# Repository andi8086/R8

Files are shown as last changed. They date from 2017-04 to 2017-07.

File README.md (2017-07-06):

## Picocom configuration ##

Start picocom with:

```
picocom --send-cmd "sx -Xb" -b 19200 -d 8 --emap lfcr /dev/ttyUSB0
```

## XMODEM File transfer ##

```
REICHEL R8
6502 CPU @ 2 MHz
32K RAM         
MONITOR (c)1976 Steve Wozniak
ADAPTED 2017 Andreas J. Reichel
\                              
F900R
F900: 20XMOD
CCCC
*** file: /home/andreas/Projects/6502/testprogs/test1.bin
$ sx -Xb /home/andreas/Projects/6502/testprogs/test1.bin 
Sending /home/andreas/Projects/6502/testprogs/test1.bin, 0 blocks: Give your local XMODEM receive command now.
Xmodem sectors/kbytes sent:   0/ 0kRetry 0: NAK on sector
Bytes Sent:    128   BPS:75                              

Transfer complete

*** exit status: 0 ***
OK
\
1000.1020
1000: A9 0E 85 20 A9 10 85 21
1008: 20 2F C0 4C 00 F8 48 69
1010: 2C 20 49 20 61 6D 20 74
1018: 68 65 20 66 69 72 73 74
1020: 20                     
1000    
1000: A9
Hi, I am the first program transfered via serial :)
\                                                  
```

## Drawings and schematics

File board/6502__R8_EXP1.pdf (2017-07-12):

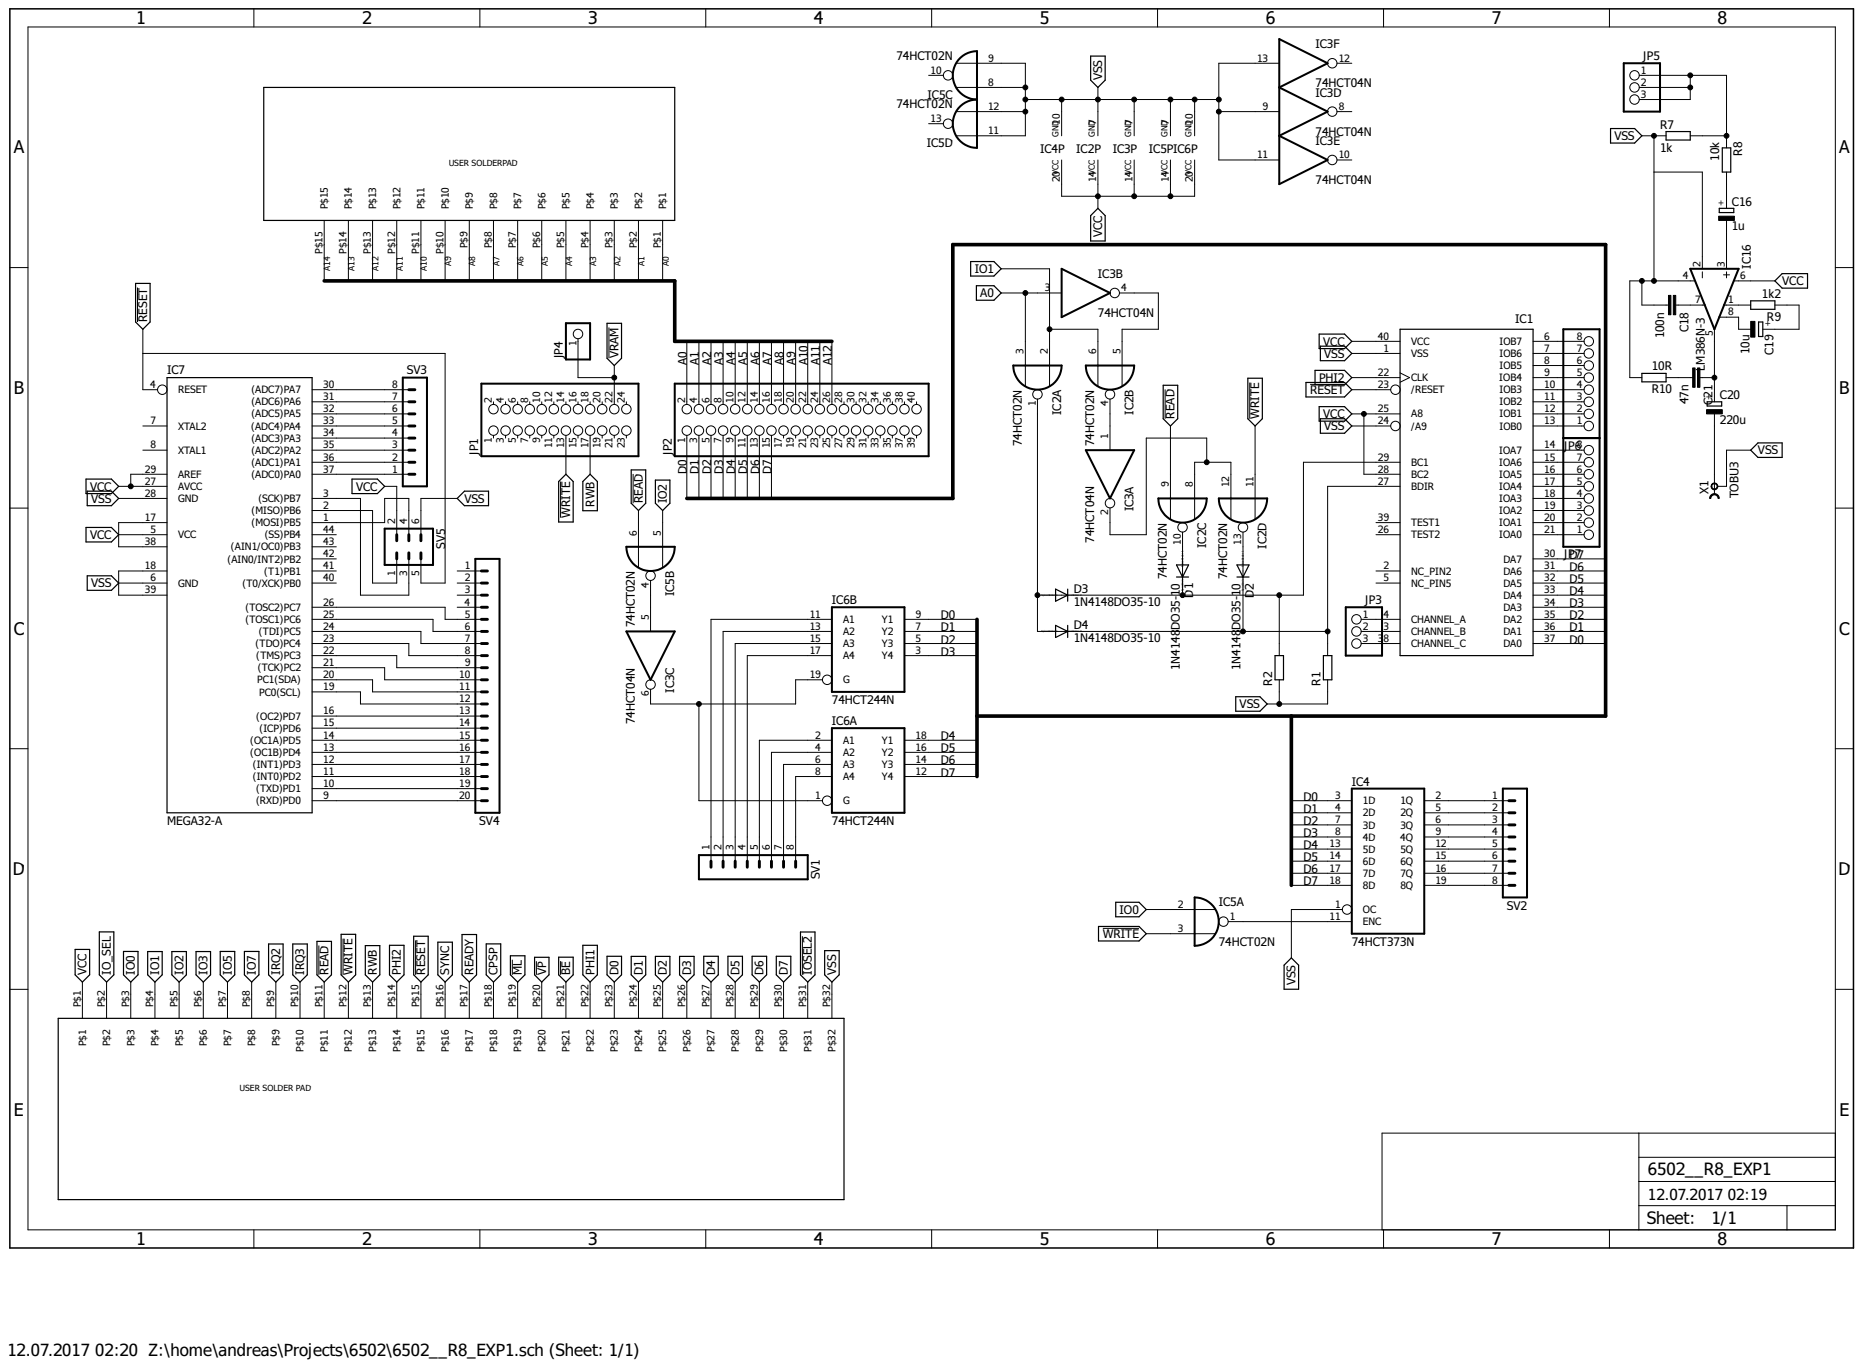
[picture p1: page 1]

5 | 44
38 | 43

SYNC READY CPSP ML VP

12.07.2017 02:20 Z:\home\andreas\Projects\6502\6502__R8_EXP1.sch (Sheet: 1/1)

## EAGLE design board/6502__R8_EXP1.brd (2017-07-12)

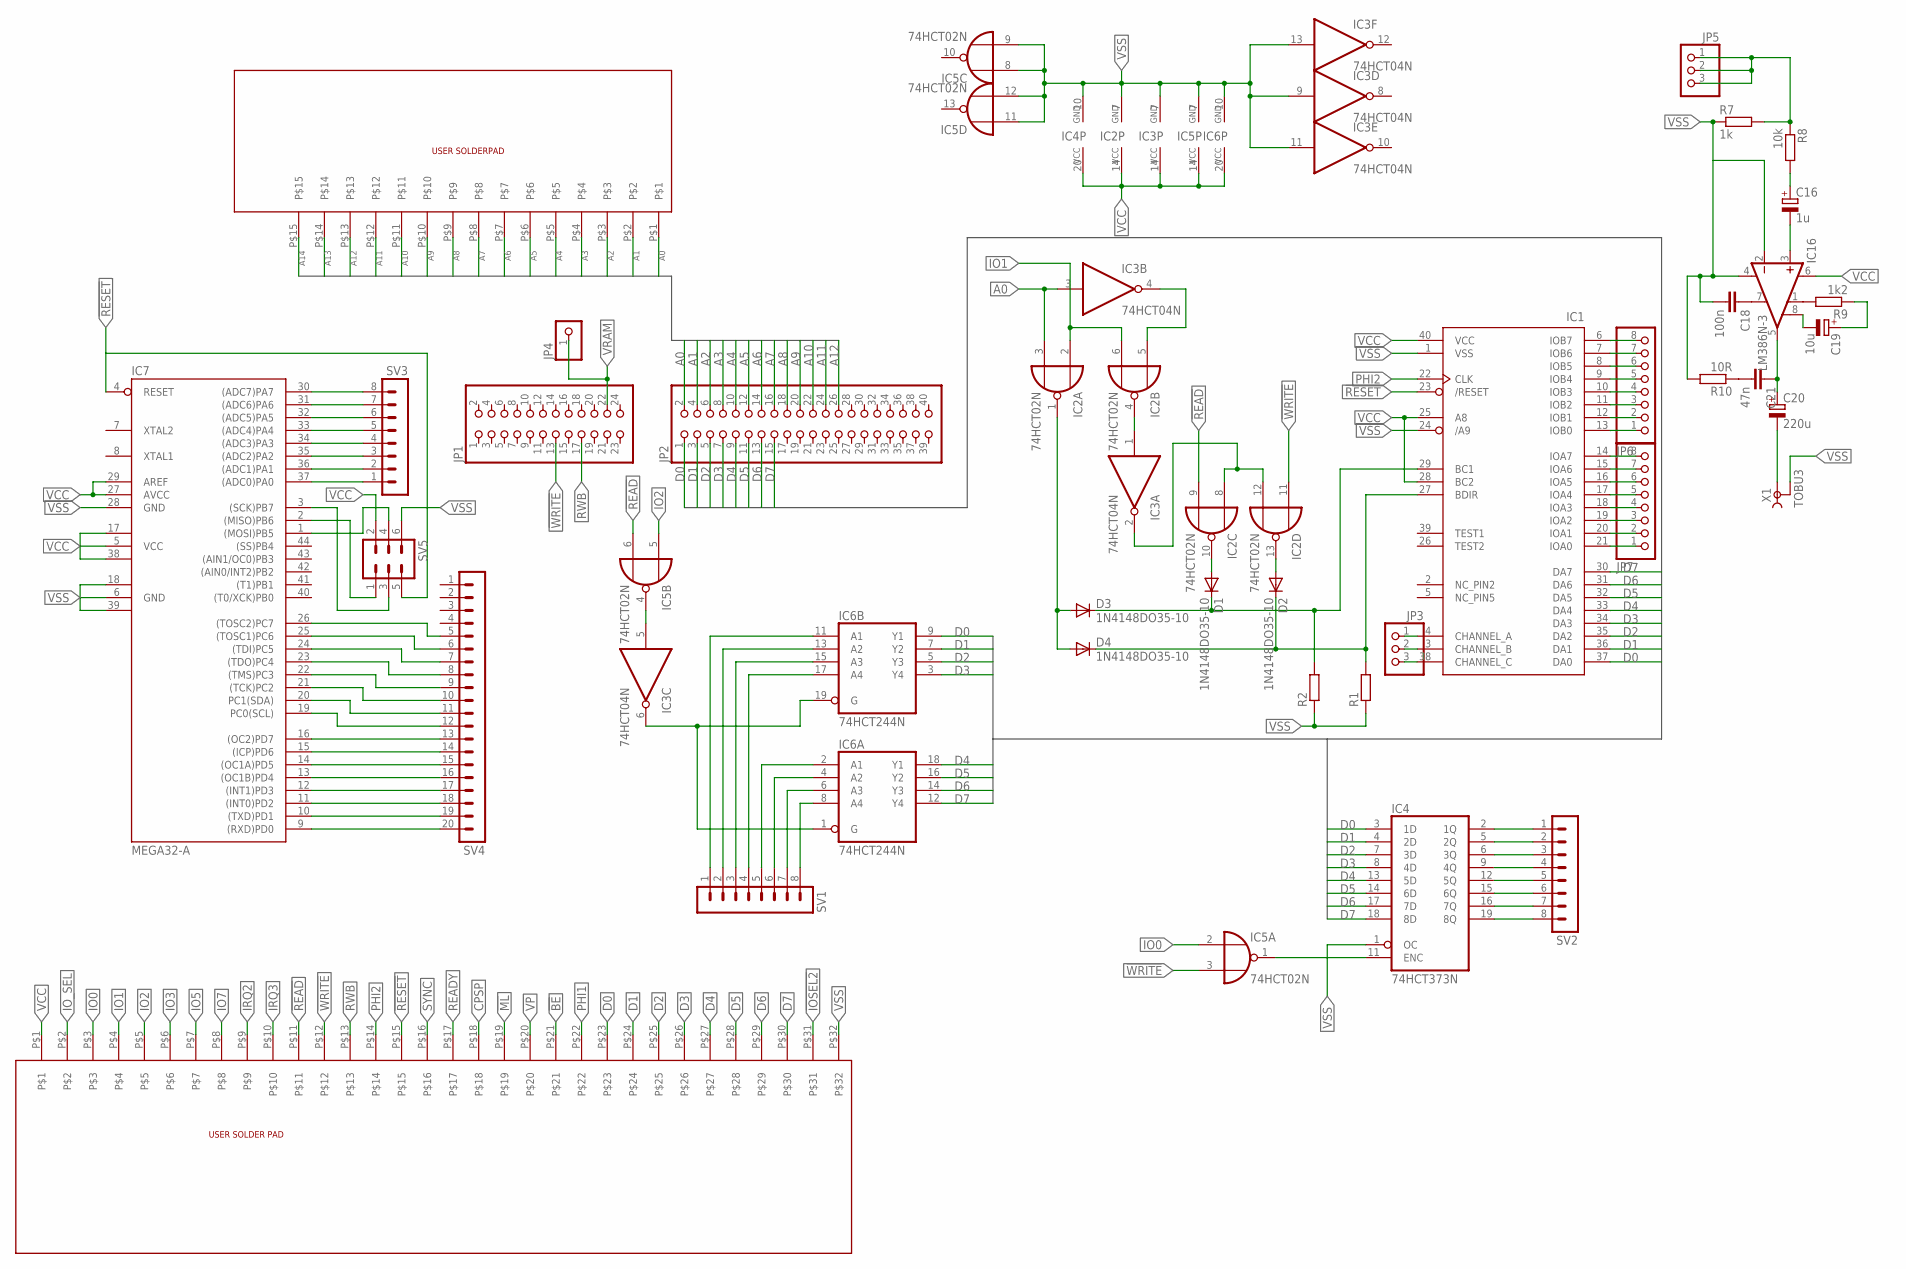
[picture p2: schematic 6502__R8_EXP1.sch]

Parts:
C16: 1u; E5-5
C18: 100n; C025-030X050
C19: 10u; E5-5
C20: 220u; E5-5
C21: 47n; C025-030X050
D1, D2, D3, D4: 1N4148DO35-10; DO35-10
IC1: AY-3-8910; DIL40
IC2, IC5: 74HCT02N; DIL14
IC3: 74HCT04N; DIL14
IC4: 74HCT373N; DIL20
IC6: 74HCT244N; DIL20
IC7: MEGA32-A; TQFP44
IC16: LM386N-3; DIL08
JP1: PINHD-2X12; 2X12
JP2: PINHD-2X20; 2X20
JP3, JP5: PINHD-1X3; 1X03
JP4: PINHD-1X1; 1X01
JP6, JP7: PINHD-1X8; 1X08
R1, R2: R-EU_0204/7; 0204/7
R7: 1k; 0207/12
R8: 10k; 0207/12
R9: 1k2; 0207/12
R10: 10R; 0207/12
SV1, SV2, SV3: MA08-1
SV4: MA20-1
SV5: MA03-2
U$2: SOLDERPAD
U$3: SOLDERPAD2
X1: TOBU3

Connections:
!BE: U$2.P$21
!IOSEL2: U$2.P$31
!ML: U$2.P$19
!READ: IC2.9 (I1), IC5.6 (I1), U$2.P$11
!RESET: IC1.23 (/RESET), IC7.4 (RESET), SV5.5, U$2.P$15
!VP: U$2.P$20
!VRAM: JP1.22, JP4.1
!WRITE: IC2.11 (I0), IC5.3 (I1), JP1.13, U$2.P$12
A0: IC2.3 (I1), IC3.3 (I), JP2.2, U$3.P$1
A1: JP2.4, U$3.P$2
A2: JP2.6, U$3.P$3
A3: JP2.8, U$3.P$4
A4: JP2.10, U$3.P$5
A5: JP2.12, U$3.P$6
A6: JP2.14, U$3.P$7
A7: JP2.16, U$3.P$8
A8: JP2.18, U$3.P$9
A9: JP2.20, U$3.P$10
A10: JP2.22, U$3.P$11
A11: JP2.24, U$3.P$12
A12: JP2.26, U$3.P$13
A13: U$3.P$14
A14: U$3.P$15
CPSP: U$2.P$18
D0: IC1.37 (DA0), IC4.3 (1D), IC6.9 (Y1), JP2.1, U$2.P$23
D1: IC1.36 (DA1), IC4.4 (2D), IC6.7 (Y2), JP2.3, U$2.P$24
D2: IC1.35 (DA2), IC4.7 (3D), IC6.5 (Y3), JP2.5, U$2.P$25
D3: IC1.34 (DA3), IC4.8 (4D), IC6.3 (Y4), JP2.7, U$2.P$26
D4: IC1.33 (DA4), IC4.13 (5D), IC6.18 (Y1), JP2.9, U$2.P$27
D5: IC1.32 (DA5), IC4.14 (6D), IC6.16 (Y2), JP2.11, U$2.P$28
D6: IC1.31 (DA6), IC4.17 (7D), IC6.14 (Y3), JP2.13, U$2.P$29
D7: IC1.30 (DA7), IC4.18 (8D), IC6.12 (Y4), JP2.15, U$2.P$30
IO0: IC5.2 (I0), U$2.P$3
IO1: IC2.2 (I0), IC2.6 (I1), U$2.P$4
IO2: IC5.5 (I0), U$2.P$5
IO3: U$2.P$6
IO5: U$2.P$7
IO7: U$2.P$8
IO_SEL: U$2.P$2
IRQ2: U$2.P$9
IRQ3: U$2.P$10
unnamed: IC4.11 (ENC), IC5.1 (O)
unnamed: IC6.11 (A1), SV1.1
unnamed: IC2.5 (I0), IC3.4 (O)
unnamed: IC2.4 (O), IC3.1 (I)
unnamed: IC2.8 (I0), IC2.12 (I1), IC3.2 (O)
unnamed: IC6.13 (A2), SV1.2
unnamed: D3.A, D4.A, IC2.1 (O)
unnamed: D1.C, D3.C, IC1.29 (BC1), R2.2
unnamed: D2.C, D4.C, IC1.27 (BDIR), R1.2
unnamed: D1.A, IC2.10 (O)
unnamed: D2.A, IC2.13 (O)
unnamed: IC6.15 (A3), SV1.3
unnamed: IC6.17 (A4), SV1.4
unnamed: IC6.2 (A1), SV1.5
unnamed: IC6.4 (A2), SV1.6
unnamed: IC6.6 (A3), SV1.7
unnamed: IC6.8 (A4), SV1.8
unnamed: IC3.5 (I), IC5.4 (O)
unnamed: IC3.6 (O), IC6.1 (G), IC6.19 (G)
unnamed: IC4.2 (1Q), SV2.1
unnamed: IC4.5 (2Q), SV2.2
unnamed: IC4.6 (3Q), SV2.3
unnamed: IC4.9 (4Q), SV2.4
unnamed: IC4.12 (5Q), SV2.5
unnamed: IC4.15 (6Q), SV2.6
unnamed: IC4.16 (7Q), SV2.7
unnamed: IC4.19 (8Q), SV2.8
unnamed: IC1.4 (CHANNEL_A), JP3.1
unnamed: IC1.3 (CHANNEL_B), JP3.2
unnamed: IC1.38 (CHANNEL_C), JP3.3
unnamed: IC1.13 (IOB0), JP6.1
unnamed: IC7.37 ((ADC0)PA0), SV3.1
unnamed: IC7.36 ((ADC1)PA1), SV3.2
unnamed: IC7.35 ((ADC2)PA2), SV3.3
unnamed: IC7.9 ((RXD)PD0), SV4.20
unnamed: IC7.10 ((TXD)PD1), SV4.19
unnamed: IC7.11 ((INT0)PD2), SV4.18
unnamed: IC7.12 ((INT1)PD3), SV4.17
unnamed: IC7.13 ((OC1B)PD4), SV4.16
unnamed: IC7.14 ((OC1A)PD5), SV4.15
unnamed: IC7.15 ((ICP)PD6), SV4.14
unnamed: IC7.16 ((OC2)PD7), SV4.13
unnamed: IC7.19 (PC0(SCL)), SV4.12
unnamed: IC7.20 (PC1(SDA)), SV4.11
unnamed: IC7.21 ((TCK)PC2), SV4.10
unnamed: IC7.22 ((TMS)PC3), SV4.9
unnamed: IC7.23 ((TDO)PC4), SV4.8
unnamed: IC7.24 ((TDI)PC5), SV4.7
unnamed: IC7.25 ((TOSC1)PC6), SV4.6
unnamed: IC7.26 ((TOSC2)PC7), SV4.5
unnamed: IC7.2 ((MISO)PB6), SV5.1
unnamed: IC7.3 ((SCK)PB7), SV5.3
unnamed: IC7.34 ((ADC3)PA3), SV3.4
unnamed: IC7.1 ((MOSI)PB5), SV5.4
unnamed: IC7.33 ((ADC4)PA4), SV3.5
unnamed: IC7.32 ((ADC5)PA5), SV3.6
unnamed: IC7.31 ((ADC6)PA6), SV3.7
unnamed: IC7.30 ((ADC7)PA7), SV3.8
unnamed: IC1.12 (IOB1), JP6.2
unnamed: IC1.11 (IOB2), JP6.3
unnamed: IC1.10 (IOB3), JP6.4
unnamed: IC1.9 (IOB4), JP6.5
unnamed: IC1.8 (IOB5), JP6.6
unnamed: IC1.7 (IOB6), JP6.7
unnamed: IC1.6 (IOB7), JP6.8
unnamed: IC1.21 (IOA0), JP7.1
unnamed: IC1.20 (IOA1), JP7.2
unnamed: IC1.19 (IOA2), JP7.3
unnamed: IC1.18 (IOA3), JP7.4
unnamed: IC1.17 (IOA4), JP7.5
unnamed: IC1.16 (IOA5), JP7.6
unnamed: IC1.15 (IOA6), JP7.7
unnamed: IC1.14 (IOA7), JP7.8
unnamed: JP5.1, JP5.2, JP5.3, R7.2, R8.1
unnamed: C16.+, R8.2
unnamed: C16.-, IC16.3 (+IN)
unnamed: C18.1, IC16.7 (BYPASS)
unnamed: C19.-, IC16.8 (GAIN)
unnamed: IC16.1 (GAIN), R9.2
unnamed: C19.+, R9.1
unnamed: C20.-, X1.1
unnamed: C20.+, C21.1, IC16.5 (OUT)
unnamed: C21.2, R10.1
PHI1: U$2.P$22
PHI2: IC1.22 (CLK), U$2.P$14
READY: U$2.P$17
RWB: JP1.17, U$2.P$13
SYNC: U$2.P$16
VCC: IC1.25 (A8), IC1.28 (BC2), IC1.40 (VCC), IC2.14 (VCC), IC3.14 (VCC), IC4.20 (VCC), IC5.14 (VCC), IC6.20 (VCC), IC7.5 (VCC), IC7.17 (VCC1), IC7.27 (AVCC), IC7.29 (AREF), IC7.38 (VCC2), IC16.6 (VS), SV5.2, U$2.P$1

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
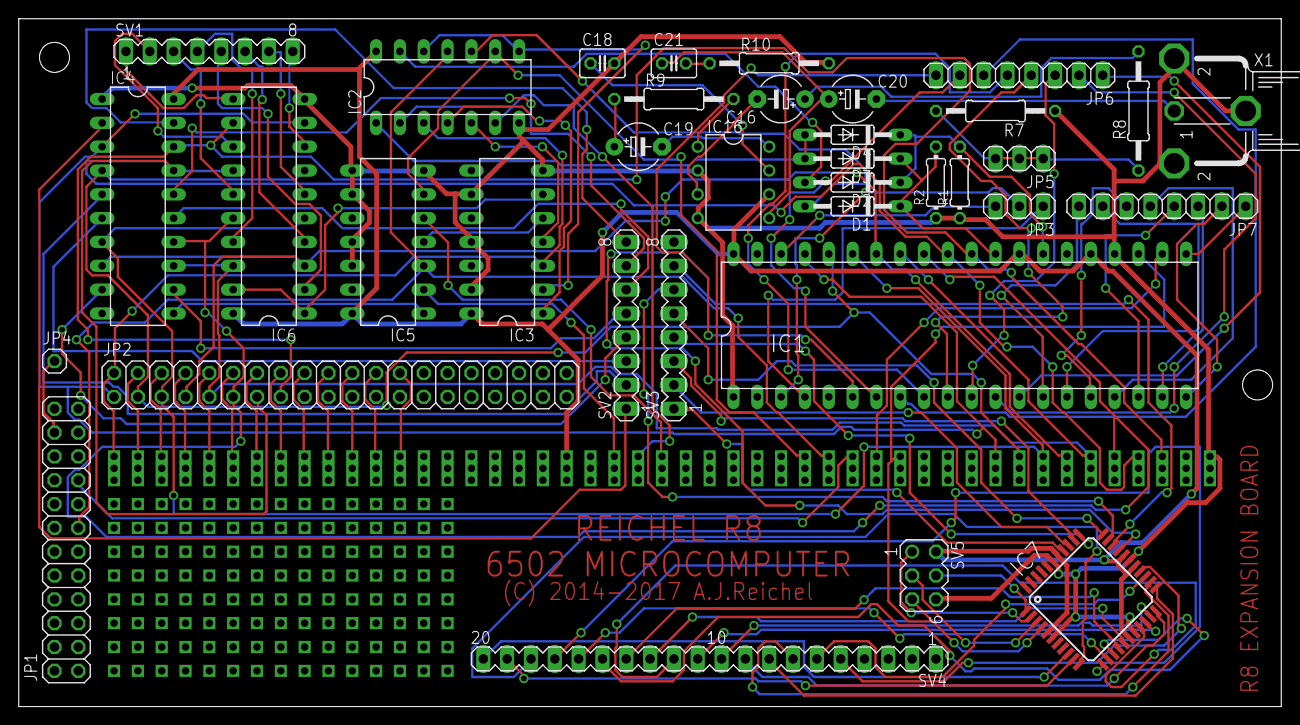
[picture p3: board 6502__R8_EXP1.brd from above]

Board: 2 copper layers, 134.6 x 73.3 mm, 38 parts (0 on the bottom side), 115 nets.

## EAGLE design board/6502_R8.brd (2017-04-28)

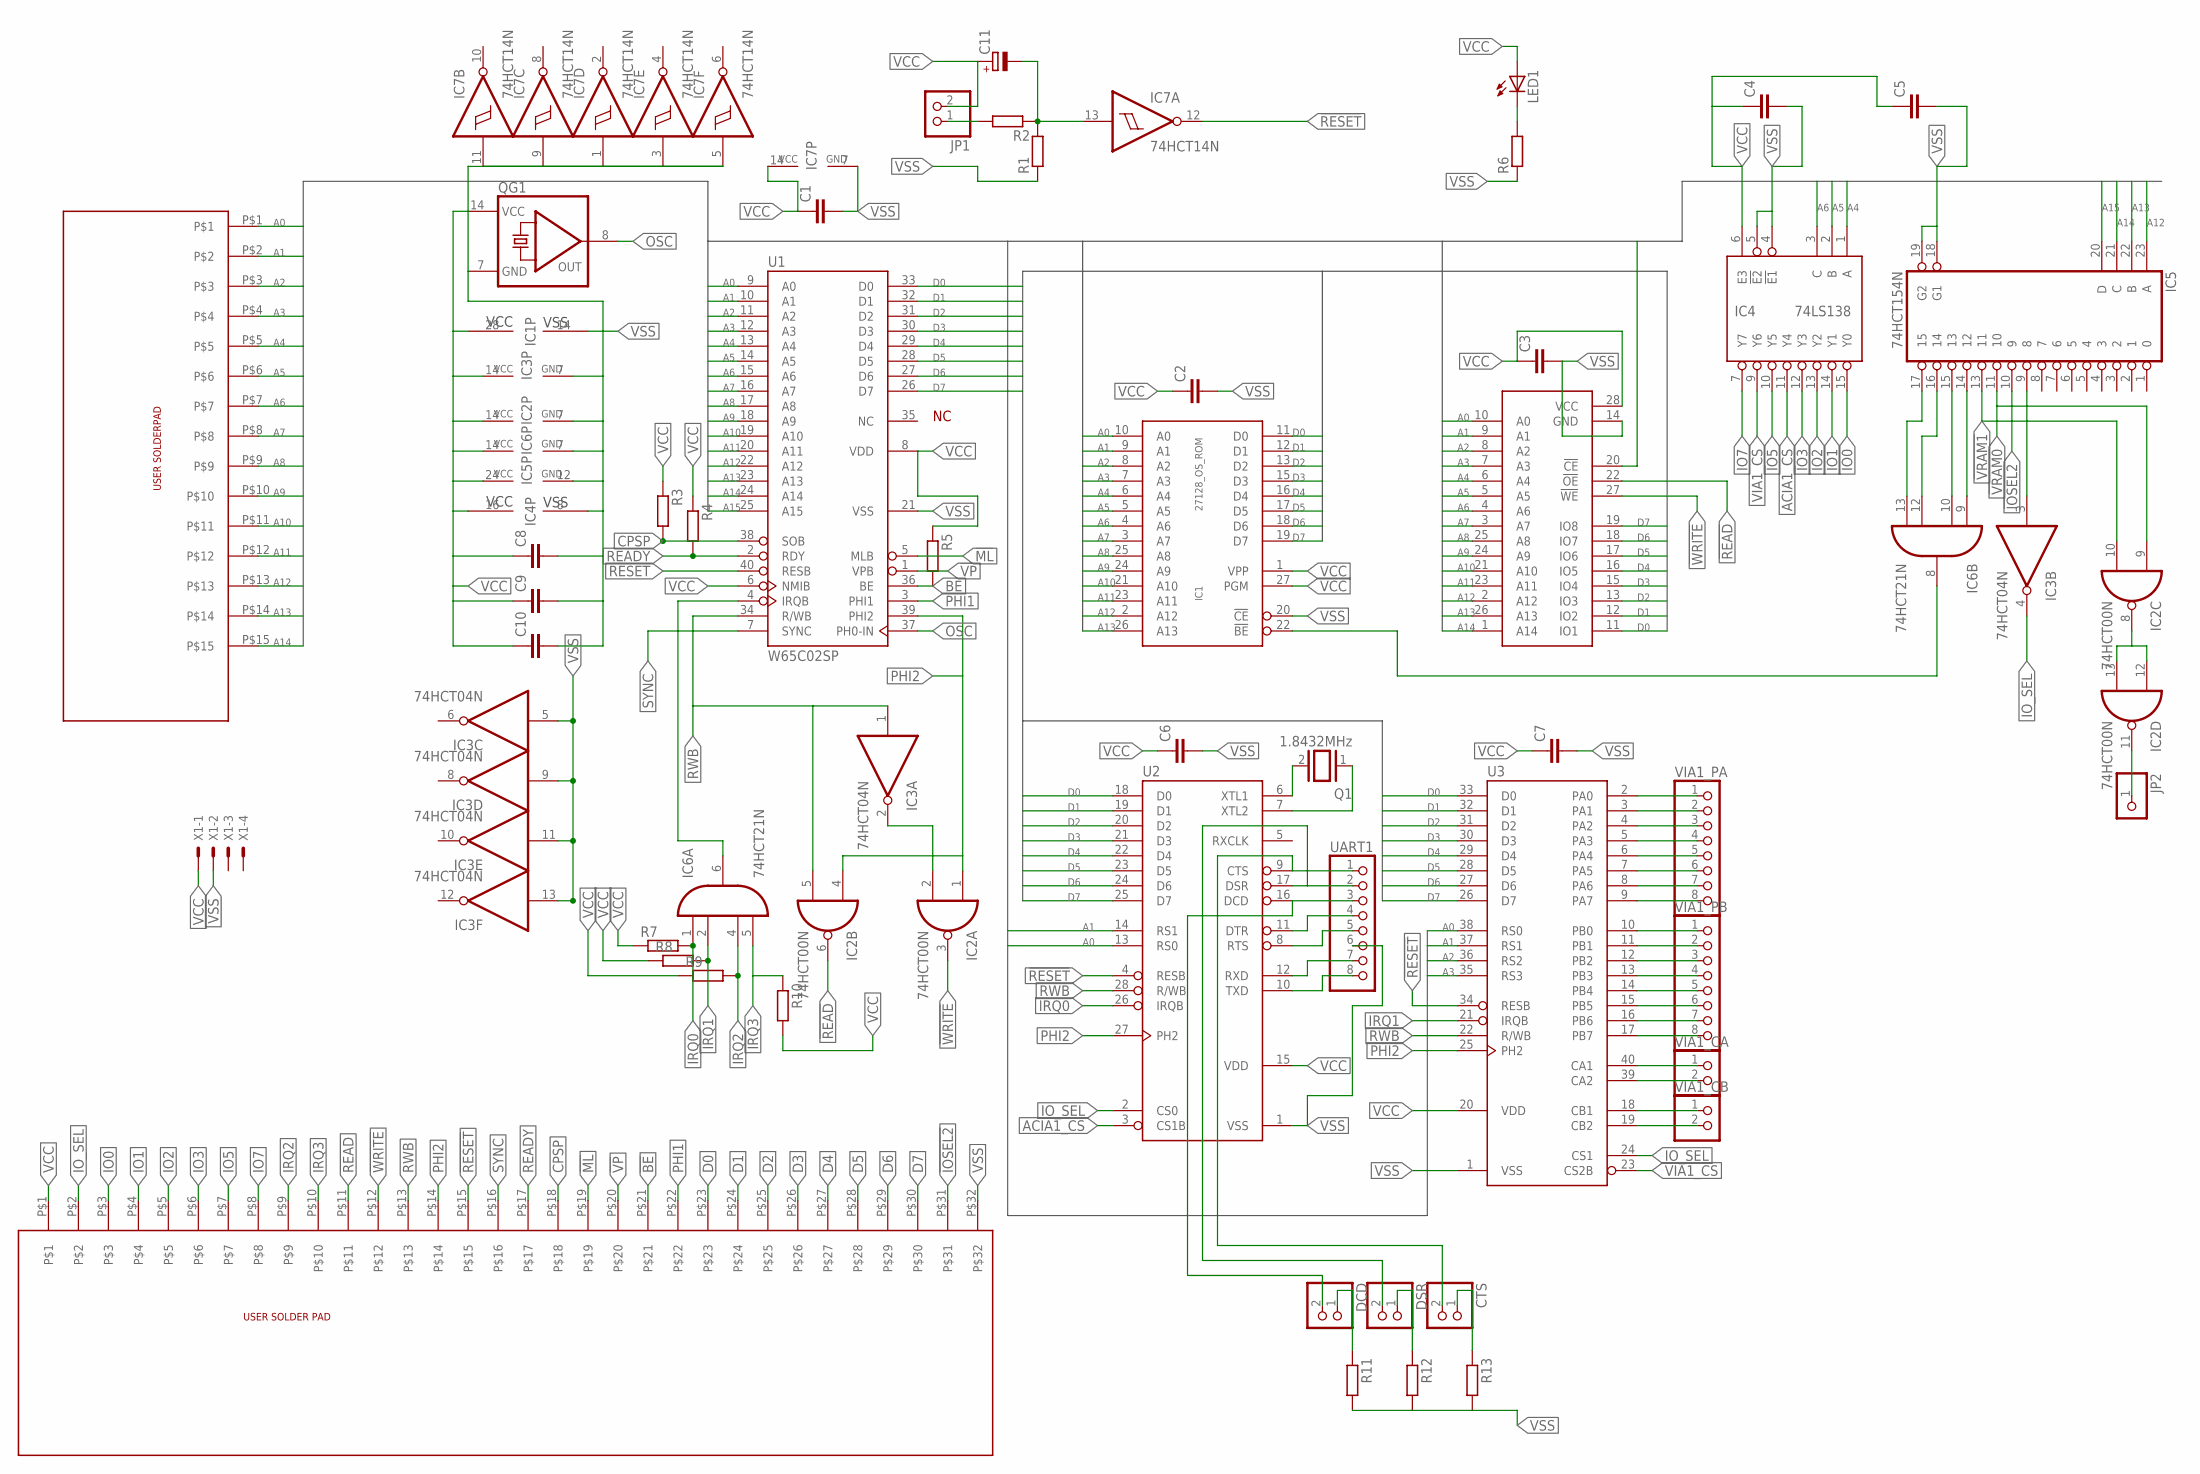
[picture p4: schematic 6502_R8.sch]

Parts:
C1, C2, C3, C4, C5, C6, C7, C8, C9, C10: C-EU025-024X044; C025-024X044
C11: CPOL-EUTT2D7; TT2D7
CTS: PINHD-1X2; 1X02
DCD: PINHD-1X2; 1X02
DSR: PINHD-1X2; 1X02
IC1: 27128_OS_ROM; DIL28
IC2: 74HCT00N; DIL14
IC3: 74HCT04N; DIL14
IC4: 74LS138; DIL16
IC5: 74HCT154N; DIL24-6
IC6: 74HCT21N; DIL14
IC7: 74HCT14N; DIL14
JP1: PINHD-1X2; 1X02
JP2: PINHD-1X1; 1X01
LED1: LED5MM
Q1: 1.8432MHz; Q
QG1: QG5860; DIL14S
R1, R2, R3, R4, R5, R6, R7, R8, R9, R10, R11, R12, R13: R-EU_0207/7; 0207/7
U1: W65C02SP; DIP-40
U2: G65SC51P; DIP-28
U3: G65SC22P; DIP-40
U$1: CXK58258AP-20; DIL28-3
U$2: SOLDERPAD
U$3: SOLDERPAD2
UART1: PINHD-1X8; 1X08
VIA1_CA, VIA1_CB: PINHD-1X2; 1X02
VIA1_PA, VIA1_PB: PINHD-1X8; 1X08
X1: KK-156-4

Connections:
!BE: U$2.P$21
!IOSEL2: IC5.10 (9), U$2.P$31
!ML: U1.5 (MLB), U$2.P$19
!READ: IC2.6 (O), U$1.22 (!OE), U$2.P$11
!RESET: IC7.12 (O), U1.40 (RESB), U2.4 (RESB), U3.34 (RESB), U$2.P$15
!VP: U1.1 (VPB), U$2.P$20
!VRAM0: IC2.9 (I0), IC5.11 (10)
!VRAM1: IC2.10 (I1), IC5.13 (11)
!WRITE: IC2.3 (O), U$1.27 (!WE), U$2.P$12
A0: IC1.10 (A0), U1.9 (A0), U2.13 (RS0), U3.38 (RS0), U$1.10 (A0), U$3.P$1
A1: IC1.9 (A1), U1.10 (A1), U2.14 (RS1), U3.37 (RS1), U$1.9 (A1), U$3.P$2
A2: IC1.8 (A2), U1.11 (A2), U3.36 (RS2), U$1.8 (A2), U$3.P$3
A3: IC1.7 (A3), U1.12 (A3), U3.35 (RS3), U$1.7 (A3), U$3.P$4
A4: IC1.6 (A4), IC4.1 (A), U1.13 (A4), U$1.6 (A4), U$3.P$5
A5: IC1.5 (A5), IC4.2 (B), U1.14 (A5), U$1.5 (A5), U$3.P$6
A6: IC1.4 (A6), IC4.3 (C), U1.15 (A6), U$1.4 (A6), U$3.P$7
A7: IC1.3 (A7), U1.16 (A7), U$1.3 (A7), U$3.P$8
A8: IC1.25 (A8), U1.17 (A8), U$1.25 (A8), U$3.P$9
A9: IC1.24 (A9), U1.18 (A9), U$1.24 (A9), U$3.P$10
A10: IC1.21 (A10), U1.19 (A10), U$1.21 (A10), U$3.P$11
A11: IC1.23 (A11), U1.20 (A11), U$1.23 (A11), U$3.P$12
A12: IC1.2 (A12), IC5.23 (A), U1.22 (A12), U$1.2 (A12), U$3.P$13
A13: IC1.26 (A13), IC5.22 (B), U1.23 (A13), U$1.26 (A13), U$3.P$14
A14: IC5.21 (C), U1.24 (A14), U$1.1 (A14), U$3.P$15
A15: IC5.20 (D), U1.25 (A15), U$1.20 (!CE)
ACIA1_CS: IC4.11 (Y4), U2.3 (CS1B)
BE: R5.2, U1.36 (BE)
CPSP: R3.2, U1.38 (SOB), U$2.P$18
D0: IC1.11 (D0), U1.33 (D0), U2.18 (D0), U3.33 (D0), U$1.11 (IO1), U$2.P$23
D1: IC1.12 (D1), U1.32 (D1), U2.19 (D1), U3.32 (D1), U$1.12 (IO2), U$2.P$24
D2: IC1.13 (D2), U1.31 (D2), U2.20 (D2), U3.31 (D2), U$1.13 (IO3), U$2.P$25
D3: IC1.15 (D3), U1.30 (D3), U2.21 (D3), U3.30 (D3), U$1.15 (IO4), U$2.P$26
D4: IC1.16 (D4), U1.29 (D4), U2.22 (D4), U3.29 (D4), U$1.16 (IO5), U$2.P$27
D5: IC1.17 (D5), U1.28 (D5), U2.23 (D5), U3.28 (D5), U$1.17 (IO6), U$2.P$28
D6: IC1.18 (D6), U1.27 (D6), U2.24 (D6), U3.27 (D6), U$1.18 (IO7), U$2.P$29
D7: IC1.19 (D7), U1.26 (D7), U2.25 (D7), U3.26 (D7), U$1.19 (IO8), U$2.P$30
IO0: IC4.15 (Y0), U$2.P$3
IO1: IC4.14 (Y1), U$2.P$4
IO2: IC4.13 (Y2), U$2.P$5
IO3: IC4.12 (Y3), U$2.P$6
IO5: IC4.10 (Y5), U$2.P$7
IO7: IC4.7 (Y7), U$2.P$8
IO_SEL: IC3.4 (O), U2.2 (CS0), U3.24 (CS1), U$2.P$2
IRQ0: IC6.1 (I0), R7.2, U2.26 (IRQB)
IRQ1: IC6.2 (I1), R8.2, U3.21 (IRQB)
IRQ2: IC6.4 (I2), R9.2, U$2.P$9
IRQ3: IC6.5 (I3), R10.1, U$2.P$10
unnamed: IC3.3 (I), IC5.9 (8)
unnamed: IC5.17 (15), IC6.13 (I3)
unnamed: IC5.16 (14), IC6.12 (I2)
unnamed: IC5.15 (13), IC6.10 (I1)
unnamed: IC5.14 (12), IC6.9 (I0)
unnamed: IC1.22 (!BE), IC6.8 (O)
unnamed: IC2.2 (I1), IC3.2 (O)
unnamed: Q1.2, U2.6 (XTL1)
unnamed: Q1.1, U2.7 (XTL2)
unnamed: IC6.6 (O), U1.4 (IRQB)
unnamed: IC2.8 (O), IC2.12 (I0), IC2.13 (I1)
unnamed: IC2.11 (O), JP2.1
unnamed: U3.2 (PA0), VIA1_PA.1
unnamed: C11.-, IC7.13 (I), R1.2, R2.1
unnamed: JP1.1, R2.2
unnamed: U3.3 (PA1), VIA1_PA.2
unnamed: U3.4 (PA2), VIA1_PA.3
unnamed: LED1.K (C), R6.2
unnamed: U3.5 (PA3), VIA1_PA.4
unnamed: U3.6 (PA4), VIA1_PA.5
unnamed: U3.7 (PA5), VIA1_PA.6
unnamed: U3.8 (PA6), VIA1_PA.7
unnamed: U3.9 (PA7), VIA1_PA.8
unnamed: U3.10 (PB0), VIA1_PB.1
unnamed: U3.11 (PB1), VIA1_PB.2
unnamed: U3.12 (PB2), VIA1_PB.3
unnamed: U3.13 (PB3), VIA1_PB.4
unnamed: U3.14 (PB4), VIA1_PB.5
unnamed: U3.15 (PB5), VIA1_PB.6
unnamed: U3.16 (PB6), VIA1_PB.7
unnamed: U3.17 (PB7), VIA1_PB.8
unnamed: U3.40 (CA1), VIA1_CA.1
unnamed: U3.39 (CA2), VIA1_CA.2
unnamed: U3.18 (CB1), VIA1_CB.1
unnamed: U3.19 (CB2), VIA1_CB.2
unnamed: U2.10 (TXD), UART1.8
unnamed: U2.12 (RXD), UART1.7
unnamed: CTS.2, U2.9 (CTS), UART1.1
unnamed: DSR.2, U2.17 (DSR), UART1.2
unnamed: DCD.2, U2.16 (DCD), UART1.3
unnamed: U2.11 (DTR), UART1.4
unnamed: U2.8 (RTS), UART1.5
unnamed: DCD.1, R11.1
unnamed: DSR.1, R12.1
unnamed: CTS.1, R13.1
OSC: QG1.8 (OUT), U1.37 (PH0-IN)
PHI1: U1.3 (PHI1), U$2.P$22
PHI2: IC2.1 (I0), IC2.4 (I0), U1.39 (PHI2), U2.27 (PH2), U3.25 (PH2), U$2.P$14
READY: R4.2, U1.2 (RDY), U$2.P$17
RWB: IC2.5 (I1), IC3.1 (I), U1.34 (R/WB), U2.28 (R/WB), U3.22 (R/WB), U$2.P$13
SYNC: U1.7 (SYNC), U$2.P$16
VCC: C1.1, C2.1, C3.1, C4.1, C5.1, C6.1, C7.1, C8.1, C9.1, C10.1, C11.+, IC1.1 (VPP), IC1.27 (PGM), IC1.28 (VCC), IC2.14 (VCC), IC3.14 (VCC), IC4.6 (E3), IC4.16 (VCC), IC5.24 (VCC), IC6.14 (VCC), IC7.14 (VCC), JP1.2, LED1.A, QG1.14 (VCC), R3.1, R4.1, R5.1, R7.1, R8.1, R9.1, R10.2, U1.6 (NMIB), U1.8 (VDD), U2.15 (VDD), U3.20 (VDD), U$1.28 (VCC), U$2.P$1, X1.1
VIA1_CS: IC4.9 (Y6), U3.23 (CS2B)
VSS: C1.2, C2.2, C3.2, C4.2, C5.2, C6.2, C7.2, C8.2, C9.2, C10.2, IC1.14 (VSS), IC1.20 (!CE), IC2.7 (GND), IC3.5 (I), IC3.7 (GND), IC3.9 (I), IC3.11 (I), IC3.13 (I), IC4.4 (!E1), IC4.5 (!E2), IC4.8 (VSS), IC5.12 (GND), IC5.18 (G1), IC5.19 (G2), IC6.7 (GND), IC7.1 (I), IC7.3 (I), IC7.5 (I), IC7.7 (GND), IC7.9 (I), IC7.11 (I), QG1.7 (GND), R1.1, R6.1, R11.2, R12.2, R13.2, U1.21 (VSS), U2.1 (VSS), U3.1 (VSS), U$1.14 (GND), U$2.P$32, UART1.6, X1.2

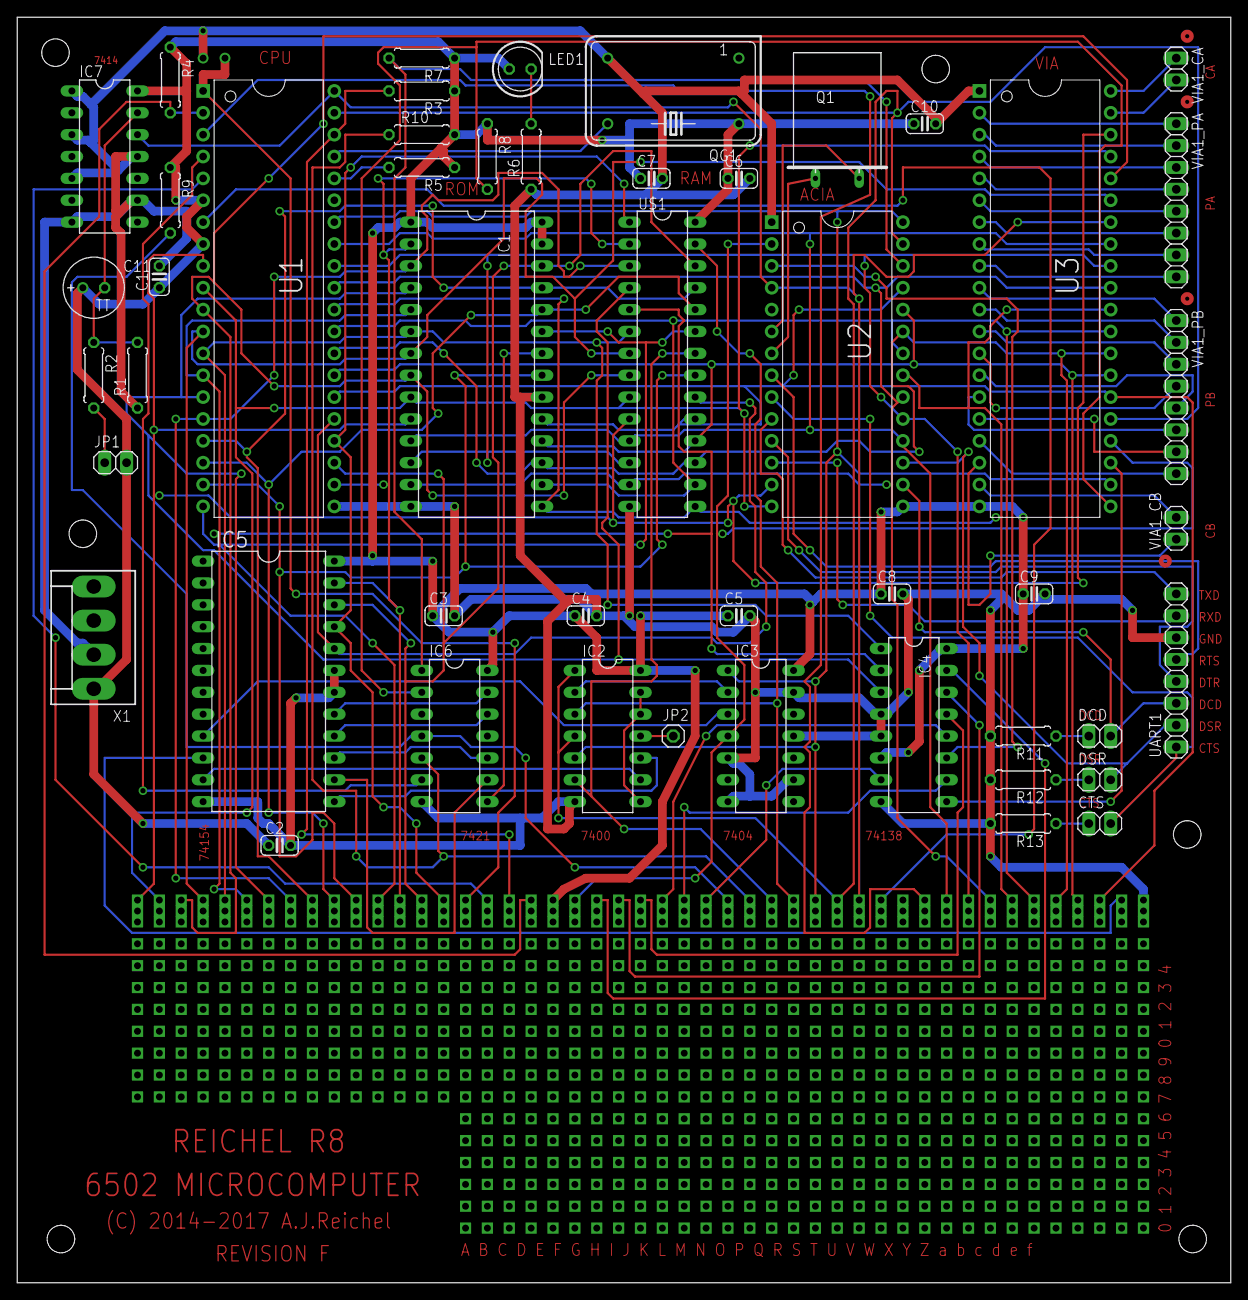
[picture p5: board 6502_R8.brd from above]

Board: 2 copper layers, 140.9 x 147.0 mm, 51 parts (0 on the bottom side), 100 nets.

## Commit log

2017-04-28 Initial commit
    Initial commit
    [6502_R8.brd, 6502_R8.sch, cbmbasic2.cfg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]
2017-04-28 LOAD: Add load command
    Add a print clone as load command to start string parsing
2017-04-28 PRINT: Fix newline bug with ","
    PRINT added a superfluous new line character after every "," and
    after the end of the output.
2017-04-28 FILE I/O: Add Kernal Stubs for Channel management
    PRINT# and INPUT# need CHKIN, CHKOUT, CLRCH
2017-07-09 Add RAM version of basic for development
    [basic.cfg, cbmbasic2.cfg]
2017-07-10 Expansion board: Add layout and schematics
    * Keyboard Connector
    * Sound Generator
    * Graphics Interface
    * Control Registers
    [6502__R8_EXP1.brd, 6502__R8_EXP1.sch]
2017-07-12 Expansion board: Improve Layout, Fix Errors
    [6502__R8_EXP1.brd, 6502__R8_EXP1.sch]
2017-12-30 Add character generator
    use 6x8 font and rotate characters to only use 192 bytes
    for all 256 codes.
    [rom.cfg]
2018-01-03 Fix bank switching in characater rendering
    Bank switching must occur if High-Byte is
    greater or equal to #$C0. It does not occur
    if it is smaller or equal to #$BF.
2018-01-06 Fix scrollup function
    Source starts at A690, i.e. it is not divisible by 256, which
    causes a bank switch inside the copy loop which is not possible
    due to timing restrictions. Thus, we have to stop one page
    before the bank end and do the rest in two extra loops.
2018-01-07 Use X Register for Bank switching in scroll func
    Use X Register to faster switch between banks to
    speed up scroll function and reduce code size.

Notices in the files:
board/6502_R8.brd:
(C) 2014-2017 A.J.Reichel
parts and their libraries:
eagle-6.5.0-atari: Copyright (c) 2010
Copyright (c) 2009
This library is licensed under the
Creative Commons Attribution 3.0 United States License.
